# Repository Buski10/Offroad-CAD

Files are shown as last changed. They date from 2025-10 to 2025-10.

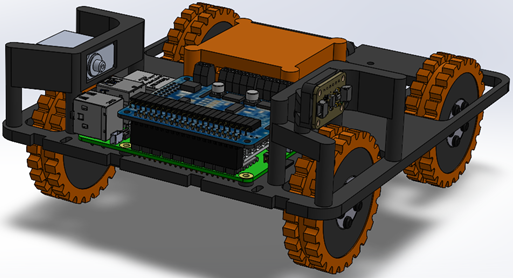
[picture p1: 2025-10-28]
workInProgress.png

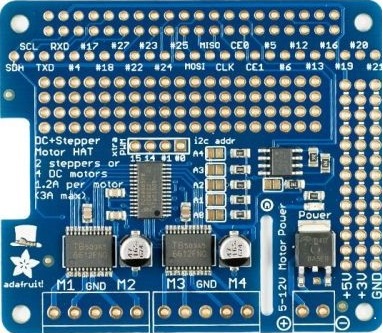
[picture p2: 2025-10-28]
Import/Stepper Hat/PCB_Image.jpg

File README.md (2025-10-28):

<p align="center">
  Team Offroad Logo
</p>

<p align="center">
  <a href="https://www.youtube.com/@Offroad-RoboCup">
    
  </a>
  <a href="https://www.instagram.com/jj_offroad_robocup/">
    
  </a>
</p>

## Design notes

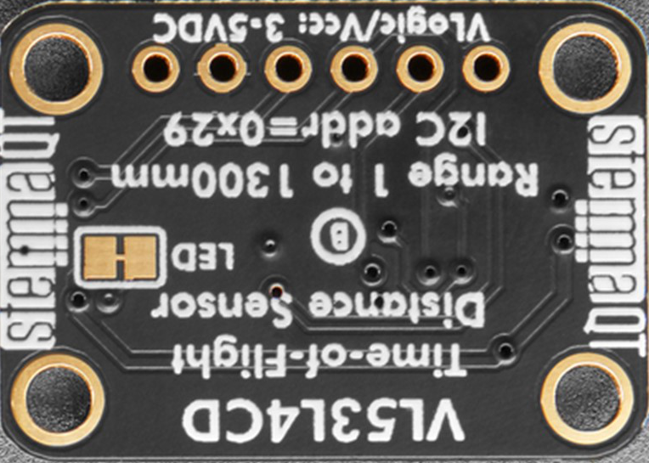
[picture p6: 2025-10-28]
Import/ToF Bilder/Bild2.jpg

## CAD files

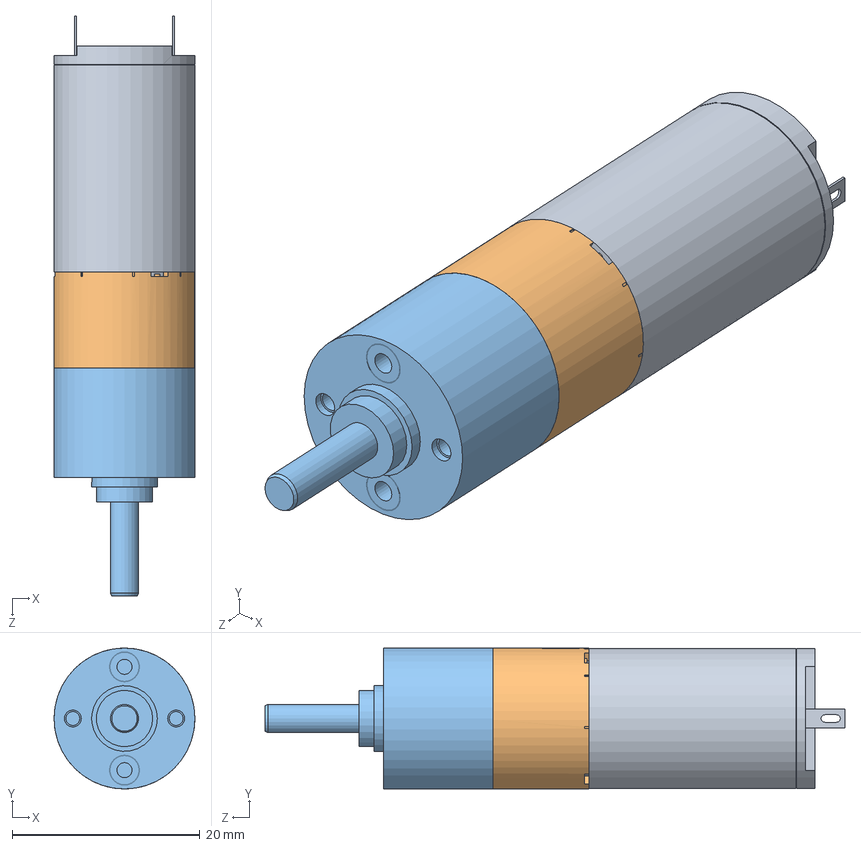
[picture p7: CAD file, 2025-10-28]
Import/Motor/Motor.SLDASM
15.0 x 15.0 x 61.8 mm
1524T_SR
15A_flange_a.stp
15A_3stage

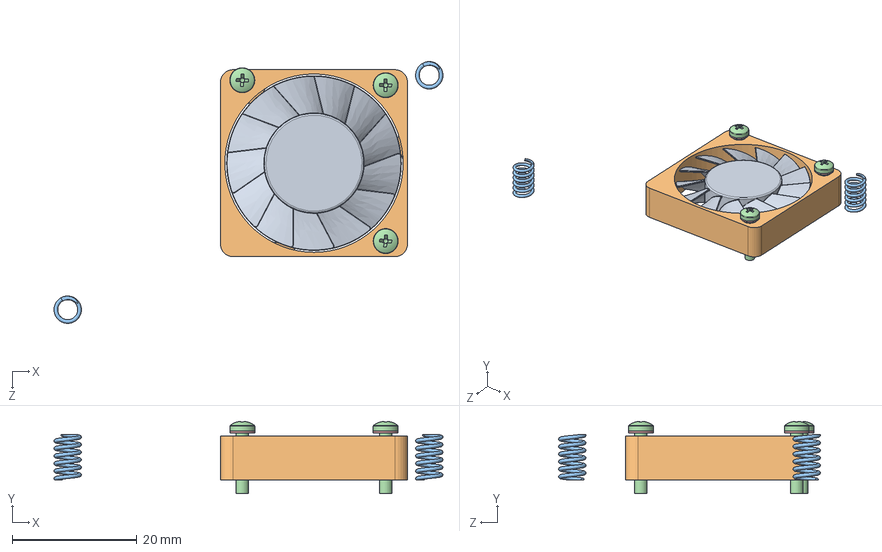
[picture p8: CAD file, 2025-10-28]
Import/RPi Active Cooler/RPi Active Cooler.SLDASM
62.4 x 11.6 x 42.0 mm
RotorBlades
MotorHouse
Spring x 2
pan head cross recess screw_din x 3
plain washer small grade a_din x 3

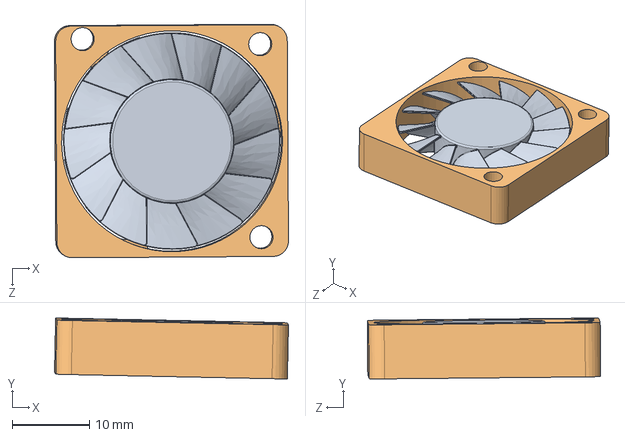
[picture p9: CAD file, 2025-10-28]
Import/RPi Active Cooler/final_assembly.SLDASM
30.3 x 7.87 x 30.2 mm
RotorBlades
MotorHouse

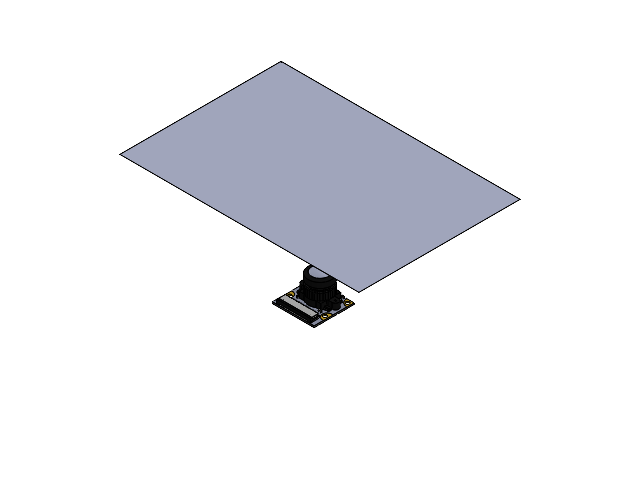
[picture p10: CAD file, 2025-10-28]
Import/rpiCamera/rpiCameraMAssembly.SLDASM
rpiCameraM
rpiCameraM_lens
kameraBlickwinkel

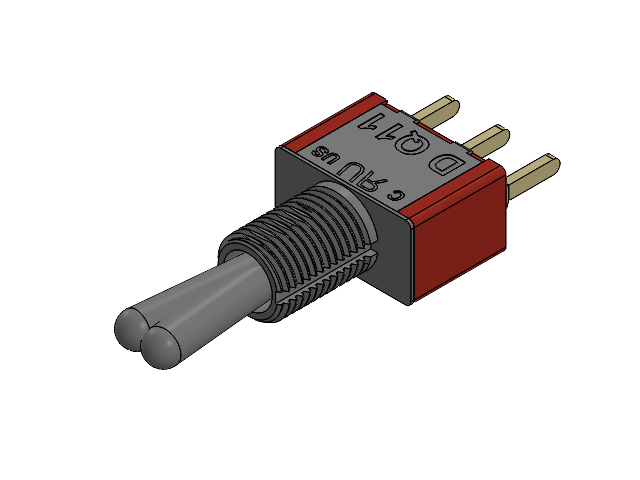
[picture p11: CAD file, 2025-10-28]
Import/Schalter/RS-PRO Schalter v5.SLDASM
Hebel.step x 2

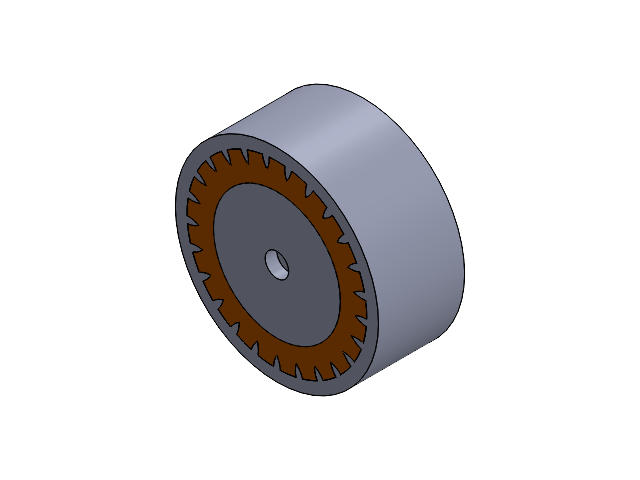
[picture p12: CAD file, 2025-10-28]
Räder/Gus.SLDASM
Silikon Rad Guss
Gussform
Gussform rausnehmen

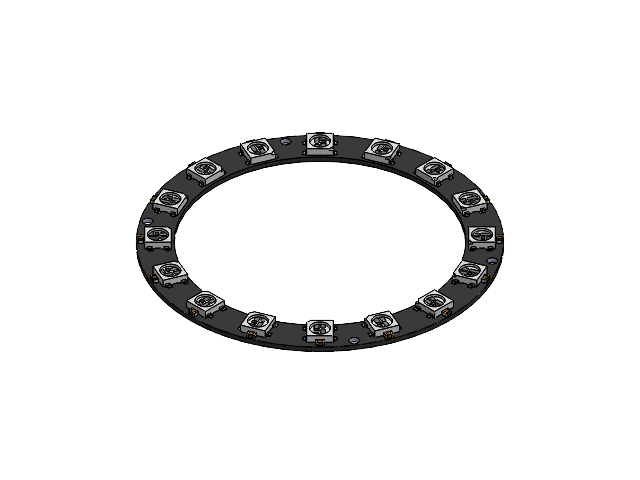
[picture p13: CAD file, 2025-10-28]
Import/ledRing/ledRing.SLDASM
LedRing
neopixel x 16
GRM188R60J226MEA0J x 16

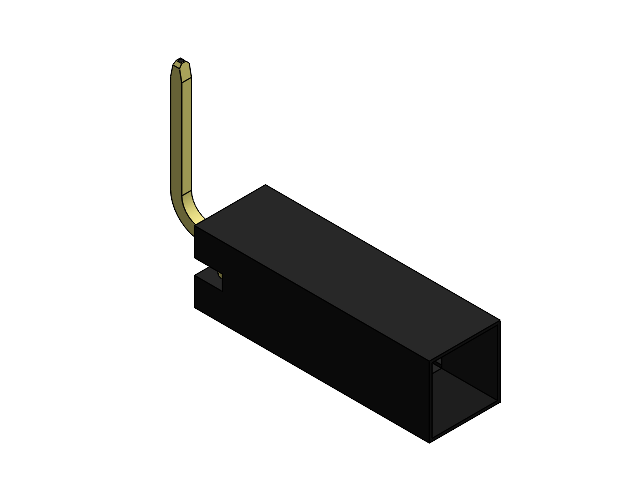
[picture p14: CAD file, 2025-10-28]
Import/Pin Header/1x1 Female Pin Header Angle.sldasm
frame_H254
pin-90deg

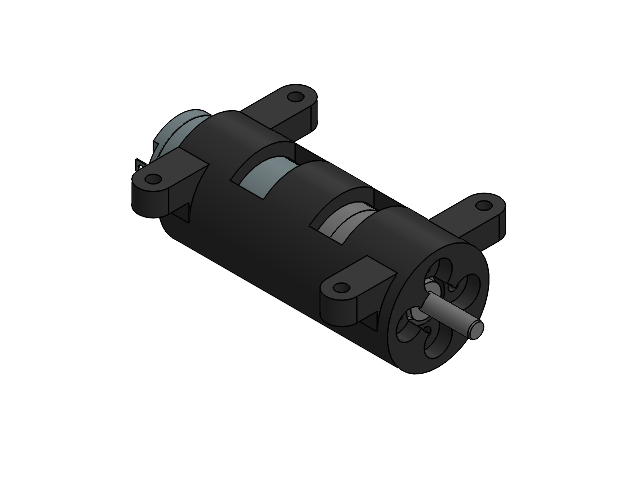
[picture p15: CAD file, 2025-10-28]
Motorhalterungen/Motor vorne.SLDASM
1524T_SR
15A_flange_a.stp
15A_3stage
Motorhalterung vorne

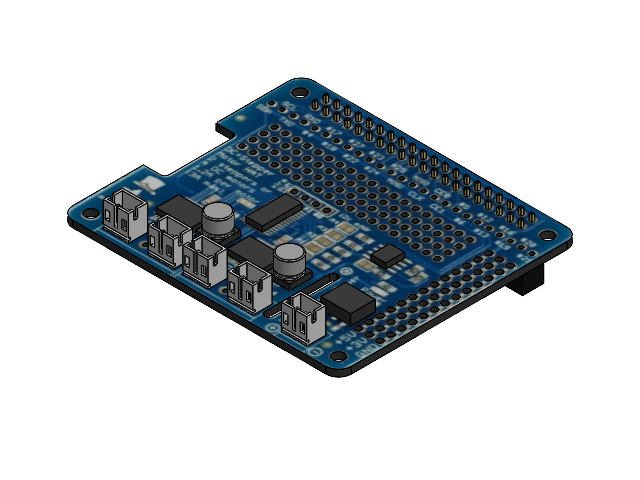
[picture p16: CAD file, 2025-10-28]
Import/Stepper Hat/AssembledAdafruitStepperHat.SLDASM
AdafruitStepperHat
40pin
JST PH2.0 2 x 5

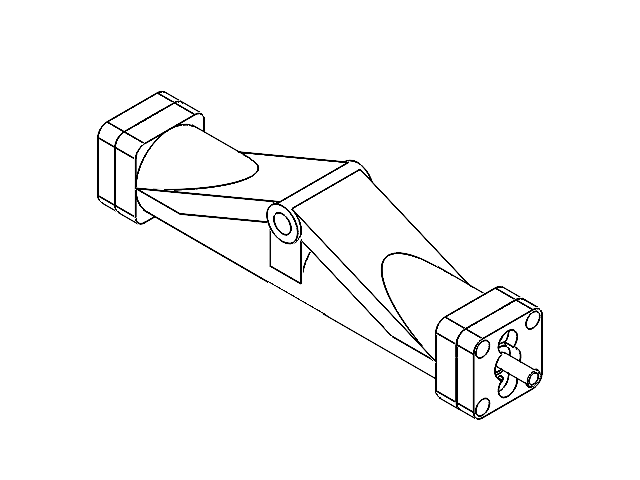
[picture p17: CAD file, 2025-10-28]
Motorhalterungen/Achse.SLDASM
1524T_SR x 2
15A_flange_a.stp x 2
15A_3stage x 2
Achse
Achse Motorhalterung
SpiegelnAchse Motorhalterung

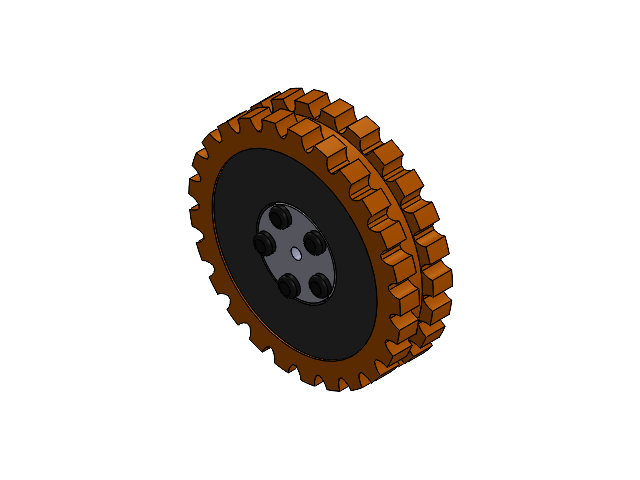
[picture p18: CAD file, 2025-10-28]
Räder/Rad.SLDASM
Silikon Rad
Felge
Felgen Adapter
Radschraube x 5

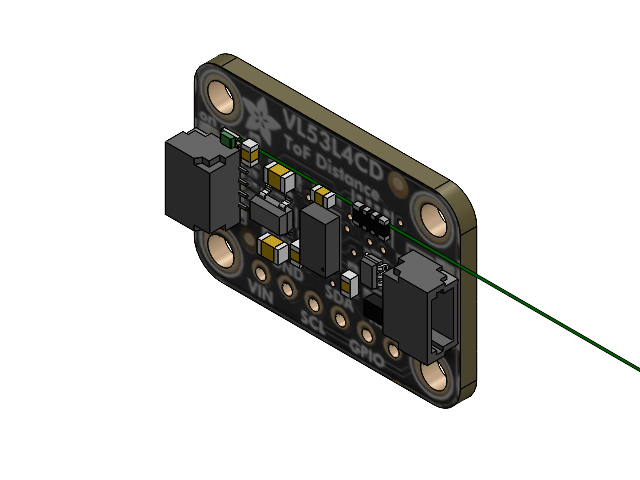
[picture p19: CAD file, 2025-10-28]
Import/5396 Adafruit VL53L4CD.SLDASM
Board_1.step
VL53L0X_1.step
1N4148.step
10uF.step x 2
LP5907-2.8_1.step
10K_2.step x 4
10K_1_1.step
BSS138_1.step
STEMMA_I2C_QT_1.step x 2
GREEN_1.step

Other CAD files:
Import/Servo S90/5396 Adafruit VL53L4CD.step.SLDASM
Import/Servo S90/Spiegeln5396 Adafruit VL53L4CD.step1.SLDASM
Import/Spiegeln5396 Adafruit VL53L4CD.SLDASM
Import/Servo S90/SpiegelnPCB Component.step.SLDASM
Import/Servo S90/Spiegeln5396 Adafruit VL53L4CD.step.SLDASM
Achsenverschluss.SLDPRT
Arduino Servo Platinen Halterung.SLDPRT
Aufsamlung/Arm.SLDPRT
Aufsamlung/Greifer.SLDPRT
Aufsamlung/SpiegelnGreifer.SLDPRT
Batteriebox.SLDPRT
Fahrgestell/Grundplatte.SLDPRT
Fahrgestell/Kamerabox.SLDPRT
Greifer Servo Halterung.SLDPRT
Greifer andere Seite Halterung.SLDPRT
Griff.SLDPRT
Hintere ToF Halterung.SLDPRT
Import/5V, 5A step down.SLDPRT
Import/7.5V, 3A step down.SLDPRT
Import/AKL 230-02 Wannenstecker für AKL 249, 2-pol, RM5,08.SLDPRT
Import/AKL 249-02 Anschlussklemmensystem 2-pol, RM5,08.SLDPRT
Import/BNO055/Adafruit_BNO055.SLDPRT
Import/BNO055/Adafruit_BNO055_AP203.STEP
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

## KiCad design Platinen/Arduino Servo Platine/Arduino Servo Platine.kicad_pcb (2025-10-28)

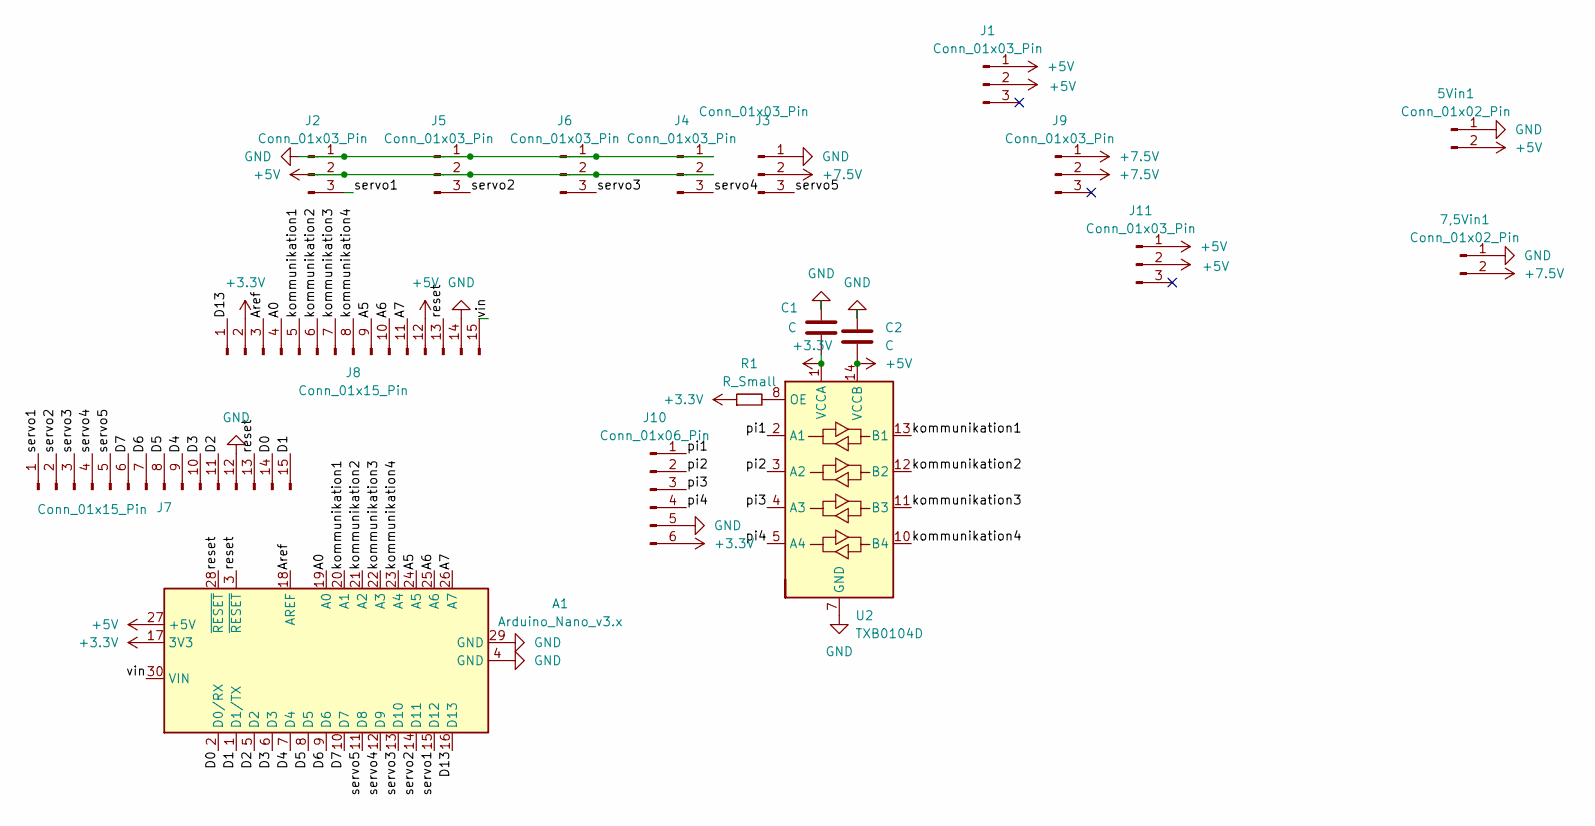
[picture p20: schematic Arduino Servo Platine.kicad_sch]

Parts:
5Vin1, 7,5Vin1: Conn_01x02_Pin; Molex_Micro-Fit_3.0_43650-0215_1x02_P3.00mm_Vertical
A1: Arduino_Nano_v3.x; Arduino_Nano
C1, C2: C; C_0805_2012Metric_Pad1.18x1.45mm_HandSolder
J1, J9, J11: Conn_01x03_Pin; SW_100SP1T1B1M1QEH
J2, J3, J4, J5, J6: Conn_01x03_Pin; JST_PH_B3B-PH-K_1x03_P2.00mm_Vertical
J7, J8: Conn_01x15_Pin; PinSocket_1x15_P2.54mm_Vertical
J10: Conn_01x06_Pin; JST_PH_B6B-PH-K_1x06_P2.00mm_Vertical
R1: R_Small; R_0805_2012Metric_Pad1.20x1.40mm_HandSolder
U2: TXB0104D; D14

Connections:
+3.3V: A1.17 (3V3), C1.2, J8.2, J10.6, R1.1, U2.1 (VCCA)
+5V: 5Vin1.2, A1.27 (+5V), C2.2, J1.1, J1.2, J2.2, J4.2, J5.2, J6.2, J8.12, J11.1, J11.2, U2.14 (VCCB)
+7.5V: 7,5Vin1.2, J3.2, J9.1, J9.2
/A0: A1.19 (A0), J8.4
/A5: A1.24 (A5), J8.9
/A6: A1.25 (A6), J8.10
/A7: A1.26 (A7), J8.11
/Aref: A1.18 (AREF), J8.3
/D0: A1.2 (D0/RX), J7.14
/D1: A1.1 (D1/TX), J7.15
/D2: A1.5 (D2), J7.11
/D3: A1.6 (D3), J7.10
/D4: A1.7 (D4), J7.9
/D5: A1.8 (D5), J7.8
/D6: A1.9 (D6), J7.7
/D7: A1.10 (D7), J7.6
/D13: A1.16 (D13), J8.1
/kommunikation1: A1.20 (A1), J8.5, U2.13 (B1)
/kommunikation2: A1.21 (A2), J8.6, U2.12 (B2)
/kommunikation3: A1.22 (A3), J8.7, U2.11 (B3)
/kommunikation4: A1.23 (A4), J8.8, U2.10 (B4)
/pi1: J10.1, U2.2 (A1)
/pi2: J10.2, U2.3 (A2)
/pi3: J10.3, U2.4 (A3)
/pi4: J10.4, U2.5 (A4)
/reset: A1.3 (~RESET), A1.28 (~RESET), J7.13, J8.13
/servo1: A1.15 (D12), J2.3, J7.1
/servo2: A1.14 (D11), J5.3, J7.2
/servo3: A1.13 (D10), J6.3, J7.3
/servo4: A1.12 (D9), J4.3, J7.4
/servo5: A1.11 (D8), J3.3, J7.5
/vin: A1.30 (VIN), J8.15
GND: 5Vin1.1, 7,5Vin1.1, A1.4 (GND), A1.29 (GND), C1.1, C2.1, J2.1, J3.1, J4.1, J5.1, J6.1, J7.12, J8.14, J10.5, U2.7 (GND)
unnamed: R1.2, U2.8 (OE)

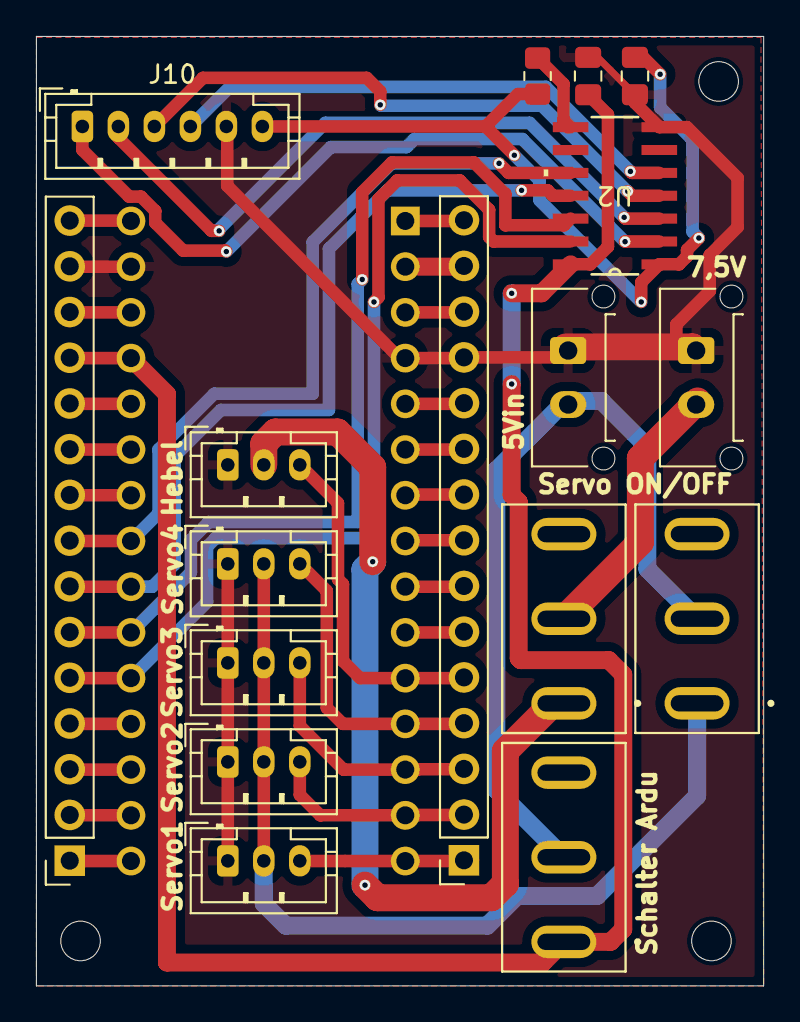
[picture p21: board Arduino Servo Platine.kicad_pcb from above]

Board: 2 copper layers, 40.4 x 52.8 mm, 18 parts (1 on the bottom side), 34 nets.

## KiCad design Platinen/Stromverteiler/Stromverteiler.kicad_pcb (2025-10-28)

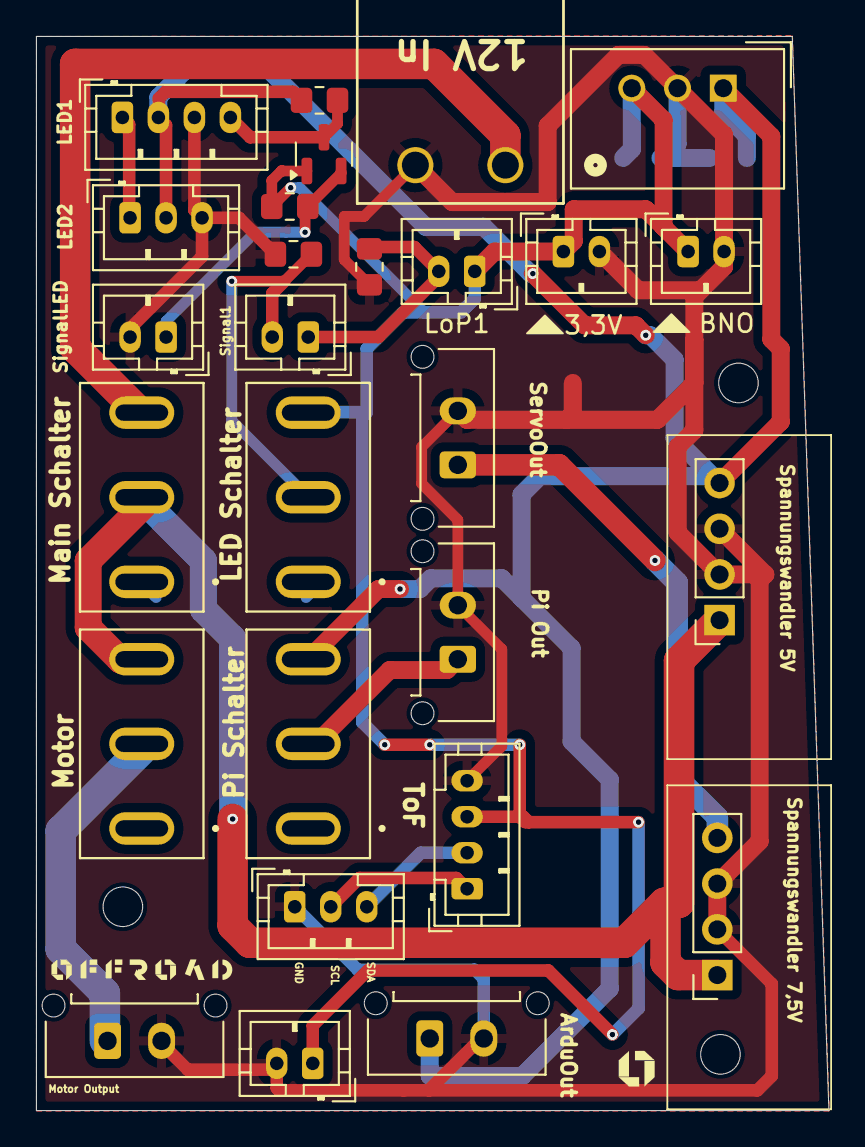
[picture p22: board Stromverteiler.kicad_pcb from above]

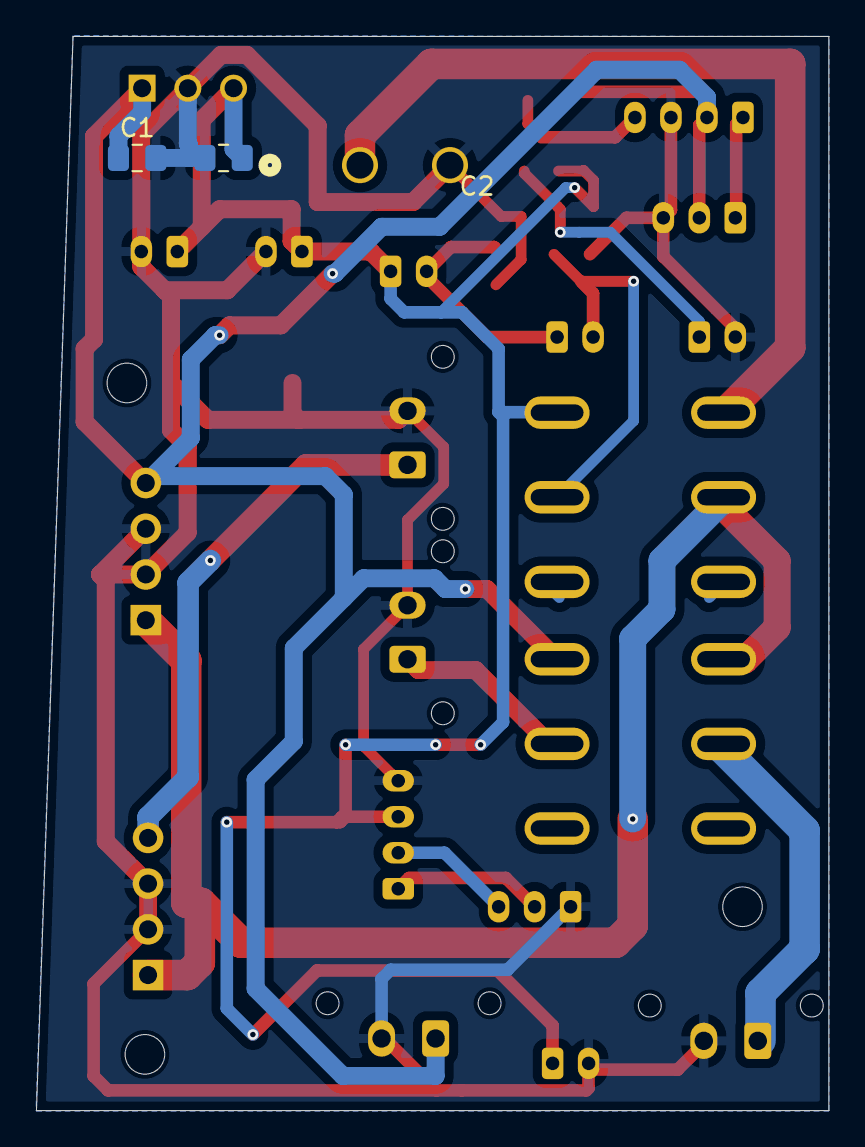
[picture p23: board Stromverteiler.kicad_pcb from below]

Board: 2 copper layers, 44.0 x 59.7 mm, 29 parts (2 on the bottom side), 12 nets.

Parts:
3,3V1: Conn_01x02_Pin; JST_PH_B2B-PH-K_1x02_P2.00mm_Vertical
3,3V2: 3,3out; JST_PH_B2B-PH-K_1x02_P2.00mm_Vertical
12Vin1: Conn_01x02_Pin; CONN_31330102_MZC
Arduino1: Conn_01x02_Pin; Molex_Micro-Fit_3.0_43650-0215_1x02_P3.00mm_Vertical
BNO1: Conn_01x02_Pin; JST_PH_B2B-PH-K_1x02_P2.00mm_Vertical
C1, C2: C; C_0805_2012Metric_Pad1.18x1.45mm_HandSolder
J1: Conn_01x03_Pin; JST_PH_B3B-PH-K_1x03_P2.00mm_Vertical
LEDAnzeige1: Conn_01x03_Pin; JST_PH_B3B-PH-K_1x03_P2.00mm_Vertical
LEDring1: Conn_01x04_Pin; JST_PH_B4B-PH-K_1x04_P2.00mm_Vertical
LoP1: Conn_01x02_Pin; JST_PH_B2B-PH-K_1x02_P2.00mm_Vertical
MotorOutput1: Conn_01x02_Pin; Molex_Micro-Fit_3.0_43650-0215_1x02_P3.00mm_Vertical
Output1: Conn_01x02_Pin; Molex_Micro-Fit_3.0_43650-0215_1x02_P3.00mm_Vertical
OutputPi1: Conn_01x02_Pin; Molex_Micro-Fit_3.0_43650-0215_1x02_P3.00mm_Vertical
Q1: BSS138; SOT-23
R1, R6, R7, R8: R_Small; R_0805_2012Metric_Pad1.20x1.40mm_HandSolder
Schalter1LED1, Schalter2Main1, Schalter3Motor1, Schalter4Pi1: Conn_01x03_Pin; SW_100SP1T1B1M1QEH
Signal1: Conn_01x02_Pin; JST_PH_B2B-PH-K_1x02_P2.00mm_Vertical
SignalLED1: Conn_01x02_Pin; JST_PH_B2B-PH-K_1x02_P2.00mm_Vertical
Spannungswandler1, Spannungswandler2: Conn_01x04_Pin; PinSocket_1x04_P2.54mm_Vertical
StemmaToF1: Conn_01x04_Pin; JST_PH_B4B-PH-K_1x04_P2.00mm_Vertical
Wandler1: TSR1-2433E; Converter_DCDC_TRACO_TSR1-xxxxE_THT

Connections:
+3.3V: 3,3V1.1, 3,3V2.1, BNO1.1, C2.2, LoP1.1, Q1.1 (G), R7.1, Schalter1LED1.3, StemmaToF1.3, Wandler1.3 (Vout)
+5V: Arduino1.1, C1.1, LEDAnzeige1.2, LEDring1.2, OutputPi1.1, R8.1, Schalter4Pi1.2, Schalter4Pi1.3, Spannungswandler1.4, Wandler1.1 (Vin)
+7.5V: Output1.1, Spannungswandler2.4
+12V: 12Vin1.1, MotorOutput1.1, Schalter2Main1.2, Schalter2Main1.3, Schalter3Motor1.2, Schalter3Motor1.3, Spannungswandler1.1, Spannungswandler2.1
GND: 3,3V1.2, 3,3V2.2, 12Vin1.2, Arduino1.2, BNO1.2, C1.2, C2.1, J1.1, LEDAnzeige1.3, LEDring1.3, MotorOutput1.2, Output1.2, OutputPi1.2, R1.2, R6.2, SignalLED1.2, Spannungswandler1.2, Spannungswandler1.3, Spannungswandler2.2, Spannungswandler2.3, StemmaToF1.4, Wandler1.2 (GND)
unnamed: J1.2, StemmaToF1.1
unnamed: J1.3, StemmaToF1.2
unnamed: LEDAnzeige1.1, LEDring1.1
unnamed: LEDring1.4, Q1.3 (D), R8.2
unnamed: LoP1.2, R1.1, Signal1.1
unnamed: Q1.2 (S), R7.2, SignalLED1.1
unnamed: R6.1, Schalter1LED1.2, Signal1.2

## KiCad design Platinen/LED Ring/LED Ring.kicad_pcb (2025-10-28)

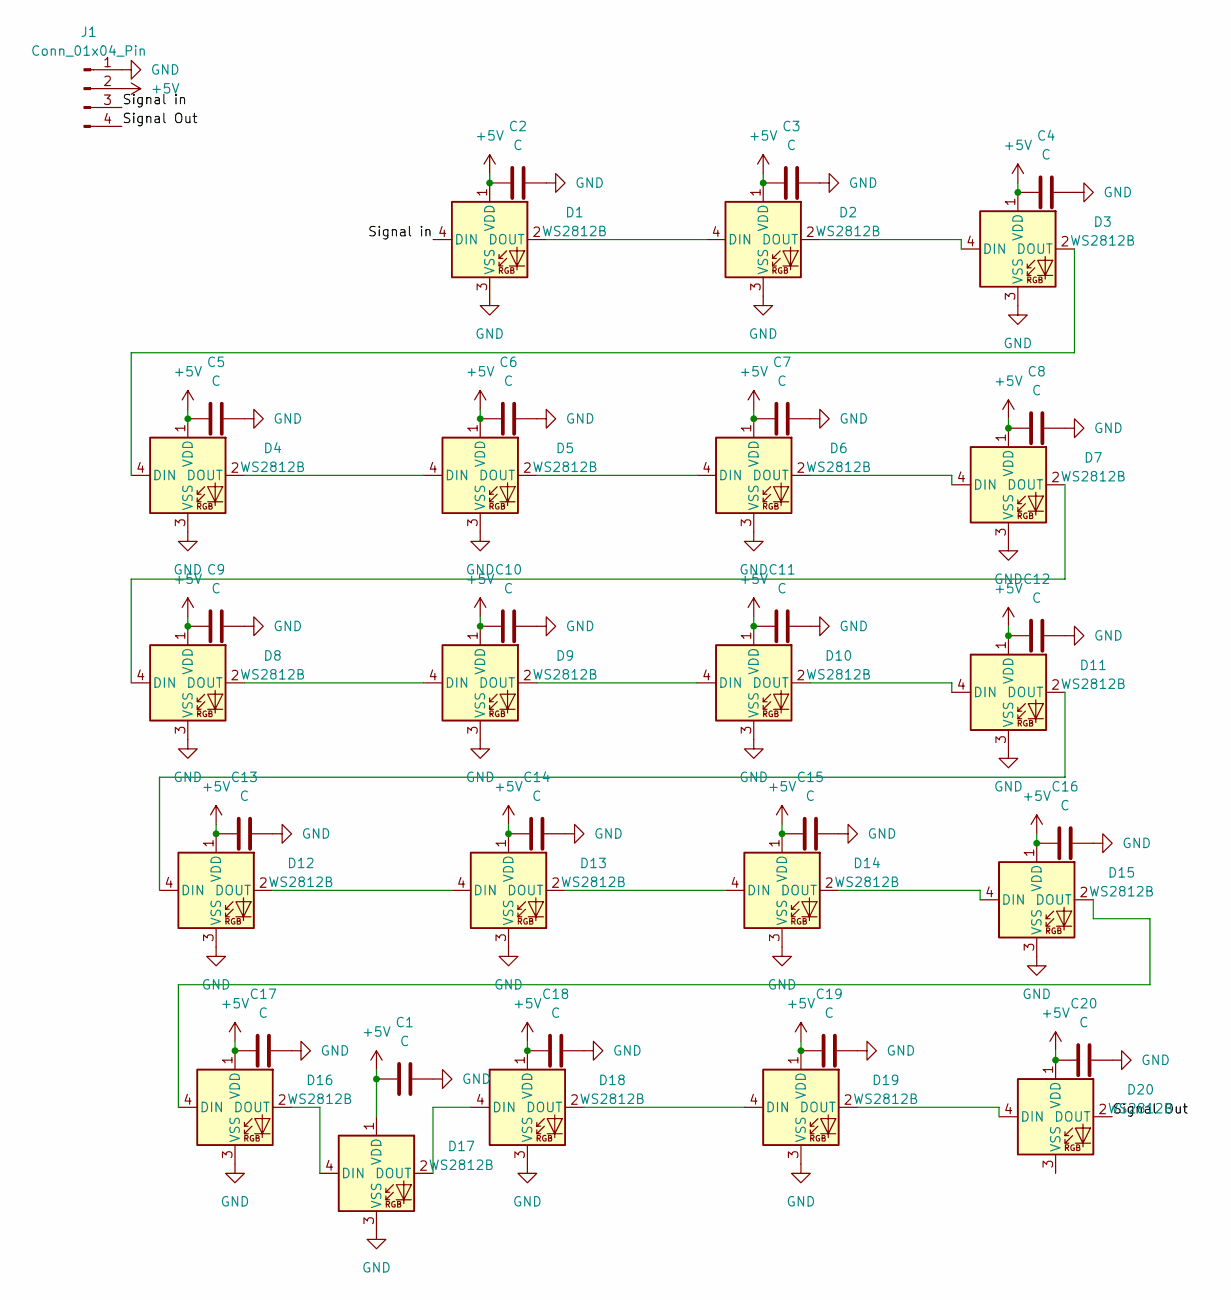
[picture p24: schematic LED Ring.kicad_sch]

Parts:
C1, C2, C3, C4, C5, C6, C7, C8, C9, C10, C11, C12, C13, C14, C15, C16, C17, C18, C19, C20: C; C_0805_2012Metric_Pad1.18x1.45mm_HandSolder
D1, D2, D3, D4, D5, D6, D7, D8, D9, D10, D11, D12, D13, D14, D15, D16, D17, D18, D19, D20: WS2812B; LED_WS2812B_PLCC4_5.0x5.0mm_P3.2mm
J1: Conn_01x04_Pin; JST_PH_B4B-PH-K_1x04_P2.00mm_Vertical

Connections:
+5V: C1.1, C2.1, C3.1, C4.1, C5.1, C6.1, C7.1, C8.1, C9.1, C10.1, C11.1, C12.1, C13.1, C14.1, C15.1, C16.1, C17.1, C18.1, C19.1, C20.1, D1.1 (VDD), D2.1 (VDD), D3.1 (VDD), D4.1 (VDD), D5.1 (VDD), D6.1 (VDD), D7.1 (VDD), D8.1 (VDD), D9.1 (VDD), D10.1 (VDD), D11.1 (VDD), D12.1 (VDD), D13.1 (VDD), D14.1 (VDD), D15.1 (VDD), D16.1 (VDD), D17.1 (VDD), D18.1 (VDD), D19.1 (VDD), D20.1 (VDD), J1.2
/Signal Out: D20.2 (DOUT), J1.4
/Signal in: D1.4 (DIN), J1.3
GND: C1.2, C2.2, C3.2, C4.2, C5.2, C6.2, C7.2, C8.2, C9.2, C10.2, C11.2, C12.2, C13.2, C14.2, C15.2, C16.2, C17.2, C18.2, C19.2, C20.2, D1.3 (VSS), D2.3 (VSS), D3.3 (VSS), D4.3 (VSS), D5.3 (VSS), D6.3 (VSS), D7.3 (VSS), D8.3 (VSS), D9.3 (VSS), D10.3 (VSS), D11.3 (VSS), D12.3 (VSS), D13.3 (VSS), D14.3 (VSS), D15.3 (VSS), D16.3 (VSS), D17.3 (VSS), D18.3 (VSS), D19.3 (VSS), J1.1
unnamed: D1.2 (DOUT), D2.4 (DIN)
unnamed: D2.2 (DOUT), D3.4 (DIN)
unnamed: D3.2 (DOUT), D4.4 (DIN)
unnamed: D4.2 (DOUT), D5.4 (DIN)
unnamed: D5.2 (DOUT), D6.4 (DIN)
unnamed: D6.2 (DOUT), D7.4 (DIN)
unnamed: D7.2 (DOUT), D8.4 (DIN)
unnamed: D8.2 (DOUT), D9.4 (DIN)
unnamed: D9.2 (DOUT), D10.4 (DIN)
unnamed: D10.2 (DOUT), D11.4 (DIN)
unnamed: D11.2 (DOUT), D12.4 (DIN)
unnamed: D12.2 (DOUT), D13.4 (DIN)
unnamed: D13.2 (DOUT), D14.4 (DIN)
unnamed: D14.2 (DOUT), D15.4 (DIN)
unnamed: D15.2 (DOUT), D16.4 (DIN)
unnamed: D16.2 (DOUT), D17.4 (DIN)
unnamed: D17.2 (DOUT), D18.4 (DIN)
unnamed: D18.2 (DOUT), D19.4 (DIN)
unnamed: D19.2 (DOUT), D20.4 (DIN)

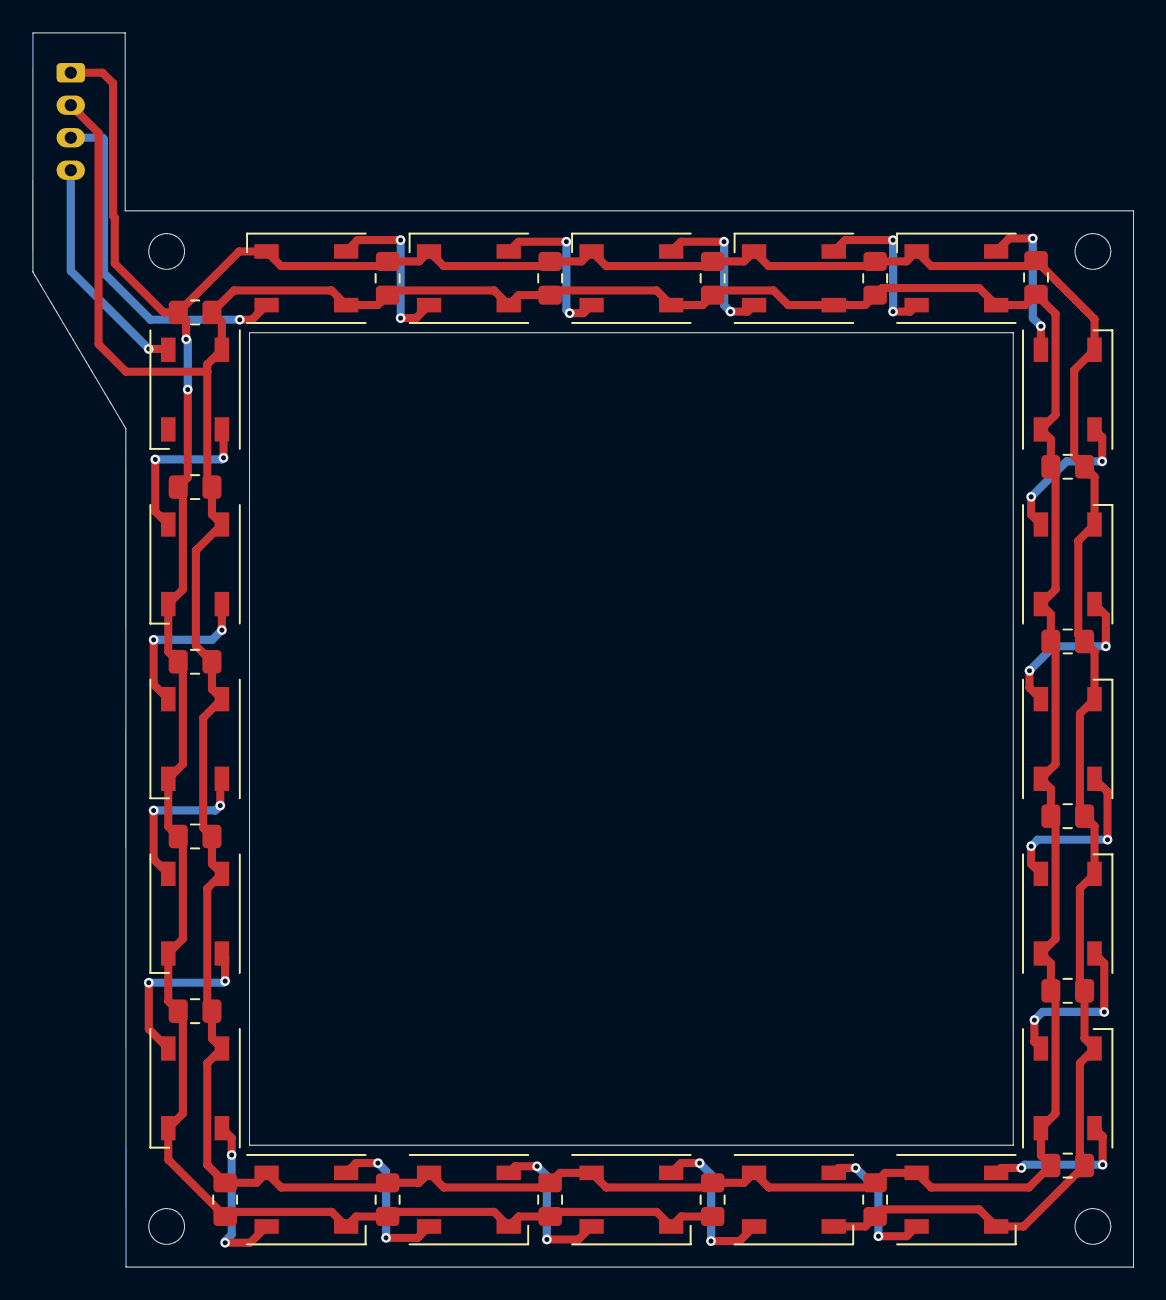
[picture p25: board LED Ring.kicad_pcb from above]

Board: 2 copper layers, 67.7 x 76.0 mm, 41 parts (1 on the bottom side), 23 nets.

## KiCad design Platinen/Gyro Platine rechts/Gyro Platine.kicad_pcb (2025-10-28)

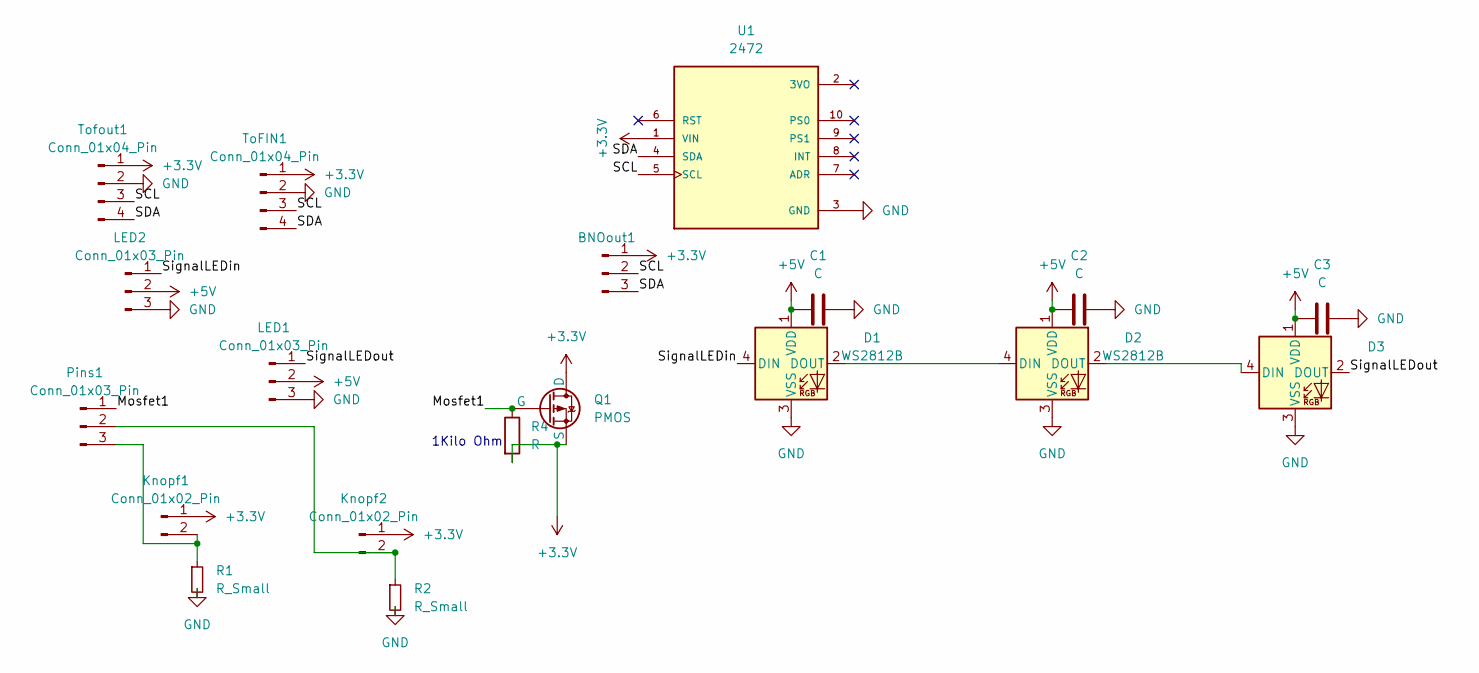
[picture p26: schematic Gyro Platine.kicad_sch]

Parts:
BNOout1: Conn_01x03_Pin; JST_PH_B3B-PH-K_1x03_P2.00mm_Vertical
C1, C2, C3: C; C_0805_2012Metric_Pad1.18x1.45mm_HandSolder
D1, D2, D3: WS2812B; LED_WS2812B_PLCC4_5.0x5.0mm_P3.2mm
Knopf1, Knopf2: Conn_01x02_Pin; JST_PH_B2B-PH-K_1x02_P2.00mm_Vertical
LED1, LED2: Conn_01x03_Pin; JST_PH_B3B-PH-K_1x03_P2.00mm_Vertical
Pins1: Conn_01x03_Pin; JST_PH_B3B-PH-K_1x03_P2.00mm_Vertical
Q1: PMOS; SOT-23_IRLML2244TRPBF_INF
R1, R2: R_Small; R_0805_2012Metric_Pad1.20x1.40mm_HandSolder
R4: R; R_0805_2012Metric_Pad1.20x1.40mm_HandSolder
ToFIN1: Conn_01x04_Pin; JST_PH_B4B-PH-K_1x04_P2.00mm_Vertical
Tofout1: Conn_01x04_Pin; JST_PH_B4B-PH-K_1x04_P2.00mm_Vertical
U1: 2472; MODULE_2472; PARTREV N/A

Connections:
+3.3V: BNOout1.1, Knopf1.1, Knopf2.1, Q1.1 (D), Q1.3 (S), R4.2, ToFIN1.1, Tofout1.1, U1.1 (VIN)
+5V: C1.1, C2.1, C3.1, D1.1 (VDD), D2.1 (VDD), D3.1 (VDD), LED1.2, LED2.2
/Mosfet1: Pins1.1, Q1.2 (G), R4.1
/SCL: BNOout1.2, ToFIN1.3, Tofout1.3, U1.5 (SCL)
/SDA: BNOout1.3, ToFIN1.4, Tofout1.4, U1.4 (SDA)
/SignalLEDin: D1.4 (DIN), LED2.1
/SignalLEDout: D3.2 (DOUT), LED1.1
GND: C1.2, C2.2, C3.2, D1.3 (VSS), D2.3 (VSS), D3.3 (VSS), LED1.3, LED2.3, R1.2, R2.2, ToFIN1.2, Tofout1.2, U1.3 (GND)
unnamed: D1.2 (DOUT), D2.4 (DIN)
unnamed: D2.2 (DOUT), D3.4 (DIN)
unnamed: Knopf1.2, Pins1.3, R1.1
unnamed: Knopf2.2, Pins1.2, R2.1

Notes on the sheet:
1Kilo Ohm

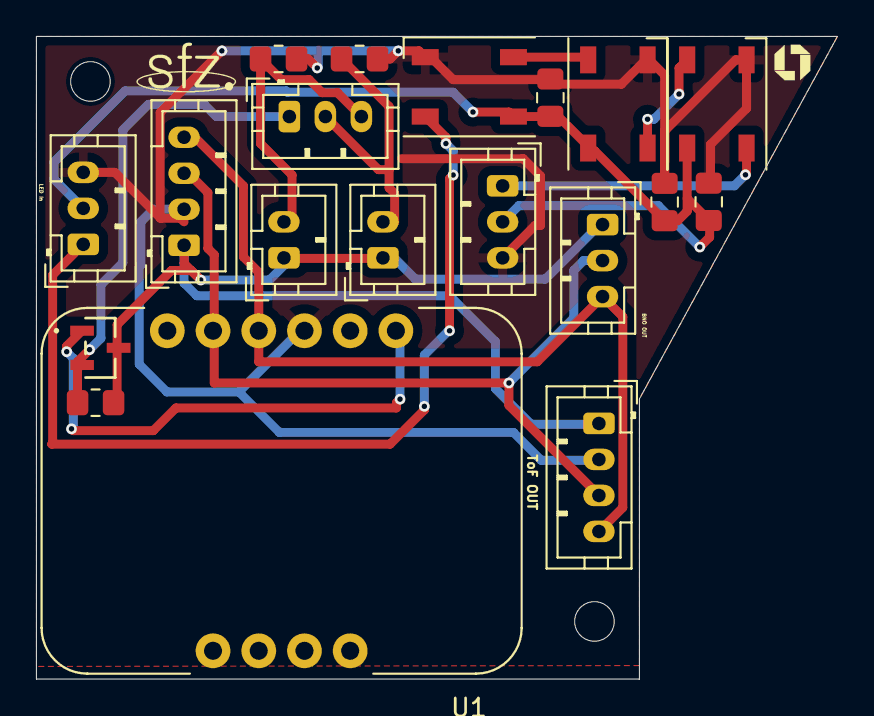
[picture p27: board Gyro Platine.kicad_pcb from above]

Board: 2 copper layers, 44.5 x 35.7 mm, 19 parts (0 on the bottom side), 12 nets.
